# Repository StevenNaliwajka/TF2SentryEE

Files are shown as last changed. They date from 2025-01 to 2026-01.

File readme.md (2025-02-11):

# NOT COMPLETE. In PROGRESS.

### To the ATF, It is structurally impossible for this design to be used with a real weapon and is not our goal. I am a law-abiding citizen.
### To Lockheed Martin, call me...
## Documentation is NOT complete. In progress
# TF2Sentry
This is the final piece of a project with [Maiikiru](https://github.com/Maiikiru) and Bradon
to create a fully functioning level one sentry from TF2 using an AIRSOFT gun.

Inbetween classes and work each of us have put countless hours into creating a cool project.

The work can be broken up into 3 repos.
- [Maiikiru's CV Repo](https://github.com/Maiikiru/TF2SentrySource) for the brain and the logic (PRIVATE for now)
- [Bradon's CAD Repo](https://github.com/ConvexBurrito5/TF2SentryCAD) for the physical CAD/STL files (PRIVATE for now)
- [Current Repo](https://github.com/ConvexBurrito5/TF2SentryEE) for circuitry and build instructions.

This repo is my work (Steven Naliwajka/ConvexBurrito5), [GitHub](https://github.com/ConvexBurrito5), [LinkedIn](https://www.linkedin.com/in/steven-naliwajka-69564929a/).

### Two options for targeting: 
1) Maiikiru has gone through and created a Computer vision (CV) repo that automatically detects and targets people: [Maiikiru's CV Repo](https://github.com/Maiikiru/TF2SentrySource)
2) I have also gone and created a remote control, [a slightly modified wrangler](https://www.youtube.com/watch?v=LYPzGNSfVRk)

To jump straight into building, see the Documentation folder.

sentry
wrangler

## Review of my learned Skills
- At a high level, what we are trying to accomplish is simple however, as always, implementation is not as easy. I have learned lots:
  - Communication!
    - I2C Communication, learned how to implement and write code to utilize it in python.
    - Radio, utilizing 2.4Ghz wireless transceiver modules to talk from the turret to the wrangler
  - Power!
    - The turret and wrangler run off batteries.
    - 7.6v, 12v, 9.2v was all required. Got to use Buck DC voltage regulators.
    - Load calculation to make sure at least 5 hours of battery life.
  - Circuitry!
    - Circuitry to be able to plug in the turret without removing the battery. Same for Wrangler.
    - Performed proper wire size calculations; by working out max amps through each.
  - Coding!
    - Python - My first real project in python. I'm typically a java slob, so it was a little bit of a culture shock. But I'm glad I got to learn.
    - Arduino(C++) - Got to continue to hone my skills.
    - Git - I was dragged into the 21st century by Maiikiru. I'm proficient at Git now.
  - 3D Design!
    - Solidworks - I am competent at solidworks now.
  - Improved my 3D printing troubleshooting skills... and gotten a sizeable print farm out of it (2 decked out Ender 3s)
  - Working with Motors/Servos with control from both I2C and PWM.

With that out of the way, lets look into what we have completed.
## Features of the project
- Detection and tracking of a person, See [Maiikiru's CV Repo](https://github.com/Maiikiru/TF2SentrySource)
- We have provided [Maiikiru's CV Repo](https://github.com/Maiikiru/TF2SentrySource) with standard API interfaces so it easy to implement multiple hardware solutions. So far:
  - Raspberry Pi 5 (Please do not use a pi4, we tried to make it work, the performance is not good) , See 'instructionFT232H.md'
  - Standard laptop using [Adafruit's FT232H Breakout](https://www.adafruit.com/product/2264), See 'instructionRaspberryPi4.md'
- There are 4 interfaces implemented in each solution
  - FiringController
    - Handles the firing by pulling logic high on a switch to bridge the motor on the airsoft gun.
  - MotorController
    - Handles all motion. Basic set of methods to move your servos.
    - Idle motion, pans slowly looking for people.
  - PeripheralController
    - Handles the leds
  - SoundController
    - Handles all the sound, runs off of the devices default speaker.
- If a switch on the wrangler is turned on, automatic movement from [Maiikiru's CV Repo](https://github.com/Maiikiru/TF2SentrySource) will be disabled and overruled.
  - Input will be solely from the joystick and the firing button on the Wrangler.

## How can you build one?
Good news! Through many sleepless nights of documentation I have
compiled instructions to build your own TF2 Turret. You can begin by 
heading to the Documentation folder

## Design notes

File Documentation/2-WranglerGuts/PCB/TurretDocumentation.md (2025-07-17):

PCB fabrication

Fast charging of 12V Lead Acid battery.
- [CN3722 Datasheet](https://www.alldatasheet.com/datasheet-pdf/pdf/1132128/CONSONANCE/CN3722.html)

USB version is differnt than PD version.
USB w/ PD 3.1 is the 'biggest power delivery' 
- 48V 5A through USB-C

Drop it down to an acceptible charging current

LeadACID battery charging current is safe @ .3(C) charging rate
where C = Amp Hours of the battery.

How to know the AH of the battery?
If given RC (Reserve Capacity) - How long the battery can cary a 25A amp draw before dropping to 10.5V.

AH = RC(min) * 25/ 60
taking the RC of a battery off [walmart](https://duckduckgo.com/y.js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)
It can sustain for 120 minutes.

so the ah (120 * 25) / 60 = 50 AH

TODO:
GET spec for CN3722
Should I use a battery not designed for CARS?
Would that give me more AH?
What is a 'general' way to go about the batteries to meet all edge cases.

POWER:
- USB3.0 w/ PD3 or PD3.1
  - Determine if that much power is worth it.
  - Verify that it is 'backwards compatable'
    - Usb 2.0 or Usb w/o PD will still allow the equipment to function.
- Convert power to 28 volts.
  - IF PD3. NO need for this, CN3722 will take the 20V.
  - If PD3.1, Need voltge drop from 48V to X?
- Charge the car battery w/ CN3722. 
  - Utilize CCCA (Coulomb Counting + Current Control Algorithm)
    - Try an implement in hardware. Worst case, link to the Main controller (ft232h)
  - Figure out max current allowed. 
    - I dont know the size of battery.
    - I dont know the AH.
    - Assume its a Lead Acid car battery still.
    - Want to get the max throughput and take advantage of supported.

BRAIN:
- Assume using FT232H for the Brain.
- Use SPI for communication protocol:
  - SPI will allow the elimination of the aurduino chip from the circuit
  - Motor Controller + nLRF24L01 will both use SPI

RADIO: 
- Assume nLRF24L01 + helper chip.
- However, Run it through SPI. 
  - I used I2C before, verify that it will work properly.

Motor Controller:
- Find an acceptable Motor controller to control two (2) PWM managed servo motors.

Switching:
- Use mosfets to switch power quickly and effectively.
-

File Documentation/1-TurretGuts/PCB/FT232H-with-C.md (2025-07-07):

Consider the idea of instead of writing w/ Python write on C
[EX of writing in C](https://www.instructables.com/FTDI-in-C/)

- NRFL01 + FT232H (SPI) + SPI MOTOR CONTROLLER 

Possible SPI motor controllers:
TMC2130, DRV8711  : Only listed few. Google.

NRFL + FT232H
[thread #1](https://www.reddit.com/r/AskElectronics/comments/1b0ci9l/nrf24l01_module_with_adafruit_ft232h/)
[thread #2](https://arduino.stackexchange.com/questions/30719/how-to-program-an-nrfl01-rf-module-that-is-connected-to-a-pc-via-a-usb-to-uart-t)
[pastebin?](https://pastebin.com/p71255yJ)

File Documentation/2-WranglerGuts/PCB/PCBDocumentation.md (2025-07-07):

Lots of references here:

5V to 3.3V regulator:
- AMS1117 is whats used in the standard "nRF24L01+PA+LNA" 5->3.3V dedicated supply.
- [AMS1117 DOCS](http://www.advanced-monolithic.com/pdf/ds1117.pdf)
- [AMS1117 EX Circuit](https://theorycircuit.com/power-circuits/voltage-regulator-circuit-5v-to-3-3v/)  

BATTERY -> 5V Regulator:
 - [MT3608 DOCS](https://www.olimex.com/Products/Breadboarding/BB-PWR-3608/resources/MT3608.pdf)
 - [MT3608 EX Circuit](https://electronics.stackexchange.com/questions/477651/mt3608-improper-output-voltage)
 - [MT3608 Fixed 5V Thread](https://www.reddit.com/r/AskElectronics/comments/1fnrpkk/mt3608_fixed_5v_output/)
 - [Selecting an Inductor DOCS](https://www.monolithicpower.com/media/document/AN122%20Selecting%20a%20Boost%20Regulator%20and%20Its%20Inductor.pdf)
 - 

Battery MGMT Circuit + Load Sharing:
- [load sharing support thread](https://forum.arduino.cc/t/solar-li-ion-charging-with-power-path-load-sharing/602451)
- [load sharing thread #2](https://electronics.stackexchange.com/questions/591555/tp4056-with-load-sharing)
- [formal load sharing writeup](https://www.thanassis.space/loadsharing.html)
- [formal load sharing writeup #2](https://blog.zakkemble.net/a-lithium-battery-charger-with-load-sharing/)
- [load sharing thread #3](https://forum.arduino.cc/t/tp4056-lithium-charger-module-modification-to-add-power-sharing/1008473)
- [TP4056 load sharing writeup #3](https://www.best-microcontroller-projects.com/tp4056-page2.html)
- [TP4056 load sharing thread #4](https://www.reddit.com/r/PrintedCircuitBoard/comments/1k89rtd/tp4056_modul_and_load_charing_circuit/)
- [TP4056 load sharing thread #5](https://electronics.stackexchange.com/questions/628664/do-these-tp4056-charging-boards-have-built-in-load-sharing)
- [TP4056 voltage output thread](https://www.reddit.com/r/AskElectronics/comments/gyblxk/what_voltage_can_the_tp4056_output/)

nLRF24L01 Radio Circuit:
- [Example Circuit](https://imgur.com/a/0xGPQbj)
- [nLRF24L01 DOCS](https://cdn.sparkfun.com/assets/3/d/8/5/1/nRF24L01P_Product_Specification_1_0.pdf)
- USE RP-SMA connector?
- [Breakout nLRF24L01](https://www.amazon.com/UMLIFE-NRF24L01-Transceiver-Wireless-Regulator/dp/B096DLGV8F)
- [Logic LEVEL shifting Thread](https://forum.arduino.cc/t/nrf24l01-pa-lna-level-shifting/1052803)
- 

ATMEGA32u4 + USBC for flashing.
- [Minimal Circuit](https://image.easyeda.com/components/396fc048a63048f4991b64bf148cbc53.png)
- [USB-C + ATmega32u4 thread](https://electronics.stackexchange.com/questions/624732/connecting-usb-c-port-with-atmega32u4-questions)
- [USB + ATmega32u4 thread #2](https://forum.arduino.cc/t/atmega32u4-usb-powered-minimal-bootloader-and-test-circuit/437689)
- [USB-C Pinout](https://www.wandkey.com/wp-content/uploads/2024/01/usb-c-pinout-diagram.png)
- [Atmega32U4RC Bootloader Thread](https://forum.arduino.cc/t/does-atmega32u4rc-au-ic-come-with-bootloader/1069773/25)
- [ATmega32u4 Base Circuit Thread](https://forum.arduino.cc/t/atmega32u4-basic-circuit-power-supply-question/543325)
- [ATmega34U4 DOCS](https://ww1.microchip.com/downloads/en/devicedoc/atmel-7766-8-bit-avr-atmega16u4-32u4_datasheet.pdf)
- [ATmega34u4 BareBones Circuit](https://forum.arduino.cc/t/atmels-atmega-32u4/158473/2)
- [USB-C Pulldown resistors](https://www.reddit.com/r/AskElectronics/comments/18svx8z/usb_typec_receptacle_can_i_connect_both_cc1_and/)
-

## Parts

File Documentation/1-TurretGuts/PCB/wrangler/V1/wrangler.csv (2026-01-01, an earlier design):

Id | Designator | Footprint | Quantity | Designation | Supplier and ref
1 | C10 | C_0201_0603Metric | 1 | 33nF
2 | D1,D3,D2,D4 | D_SMA | 4 | SS14
3 | C17,C20,C19,C18 | C_0201_0603Metric | 4 | 1pF
4 | D12,D10,D9,D11 | LED_0805_2012Metric | 4 | LED
5 | C22,C21,C29,C32,C1 | C_0201_0603Metric | 5 | .1uF
6 | C16 | C_0201_0603Metric | 1 | .3pF
7 | Q2 | SOT-23 | 1 | AO3401A
8 | C14,C8 | C_0201_0603Metric | 2 | 10nF
9 | R8,R6 | C_0805_2012Metric | 2 | 1k
10 | L3 | C_0201_0603Metric | 1 | 3.9nH
11 | R12,R13,R2,R1 | C_0805_2012Metric | 4 | 1K
12 | R3,R9 | C_0805_2012Metric | 2 | 1.2K
13 | R5 | C_0805_2012Metric | 1 | 22k
14 | R10 | C_0805_2012Metric | 1 | 220
15 | L5 | L_1206_3216Metric | 1 | 4.7uH
16 | C28,C26,C25,C27 | C_0201_0603Metric | 4 | 10uF
17 | R14 | C_0805_2012Metric | 1 | 100
18 | U8 | SOT-23-6 | 1 | DW01A
19 | R16,R17 | C_0805_2012Metric | 2 | 10K
20 | L2,L6,L4 | C_0201_0603Metric | 3 | 2.7nH
21 | C6 | C_0201_0603Metric | 1 | 1.5pF
22 | C23,C24 | C_0201_0603Metric | 2 | 22uF
23 | U9 | SOT-23-6 | 1 | MT3608
24 | C30,C11,C12,C31 | C_0201_0603Metric | 4 | 22pF
25 | R19 | C_0805_2012Metric | 1 | 330
26 | J-LED1,J-Trigger1,J-BattLED1,J-18650,J-Spare1 | 353170221 | 5 | 35317-0221
27 | R7 | C_0805_2012Metric | 1 | 2k
28 | U5 | QFN50P300X300X60-17N | 1 | RFX2401C
29 | C7 | C_0201_0603Metric | 1 | 1.0pF
30 | R15 | C_0805_2012Metric | 1 | 32.4K
31 | U6 | SOT-223-3_TabPin2 | 1 | AMS1117
32 | C5 | C_0201_0603Metric | 1 | 4.7pf
33 | C4 | C_0201_0603Metric | 1 | 2.2nF
34 | R18,R11 | C_0805_2012Metric | 2 | 5.1K
35 | J1 | USB_C_Receptacle_HRO_TYPE-C-31-M-12 | 1 | USB_C_Receptacle
36 | C9 | C_0201_0603Metric | 1 | 1nF
37 | J-Joystick1 | RHDR6W107P420_2X3_1380X960X1310P | 1 | 35317-0620
38 | C13 | C_0201_0603Metric | 1 | 220pF
39 | Y2,Y1 | Crystal_SMD_3225-4Pin_3.2x2.5mm | 2 | 16MHz
40 | U2 | SOIC-8-1EP_3.9x4.9mm_P1.27mm_EP2.41x3.3mm_ThermalVias | 1 | TP4056-42-ESOP8
41 | J-PowerSwitch1 | SHDR4W107P420_2X2_960X960X1280P | 1 | 35317-0420
42 | C15 | C_0201_0603Metric | 1 | 1uF
43 | U4 | QFN-20-1EP_4x4mm_P0.5mm_EP2.5x2.5mm | 1 | nRF24L01P
44 | L1 | C_0201_0603Metric | 1 | 8.2nH
45 | J2 | SMA_Amphenol_132289_EdgeMount | 1 | SMA-RP
46 | Q3 | SOT-23-6 | 1 | FS8205A
47 | U3 | TQFP-44_10x10mm_P0.8mm | 1 | ATmega32U4-A

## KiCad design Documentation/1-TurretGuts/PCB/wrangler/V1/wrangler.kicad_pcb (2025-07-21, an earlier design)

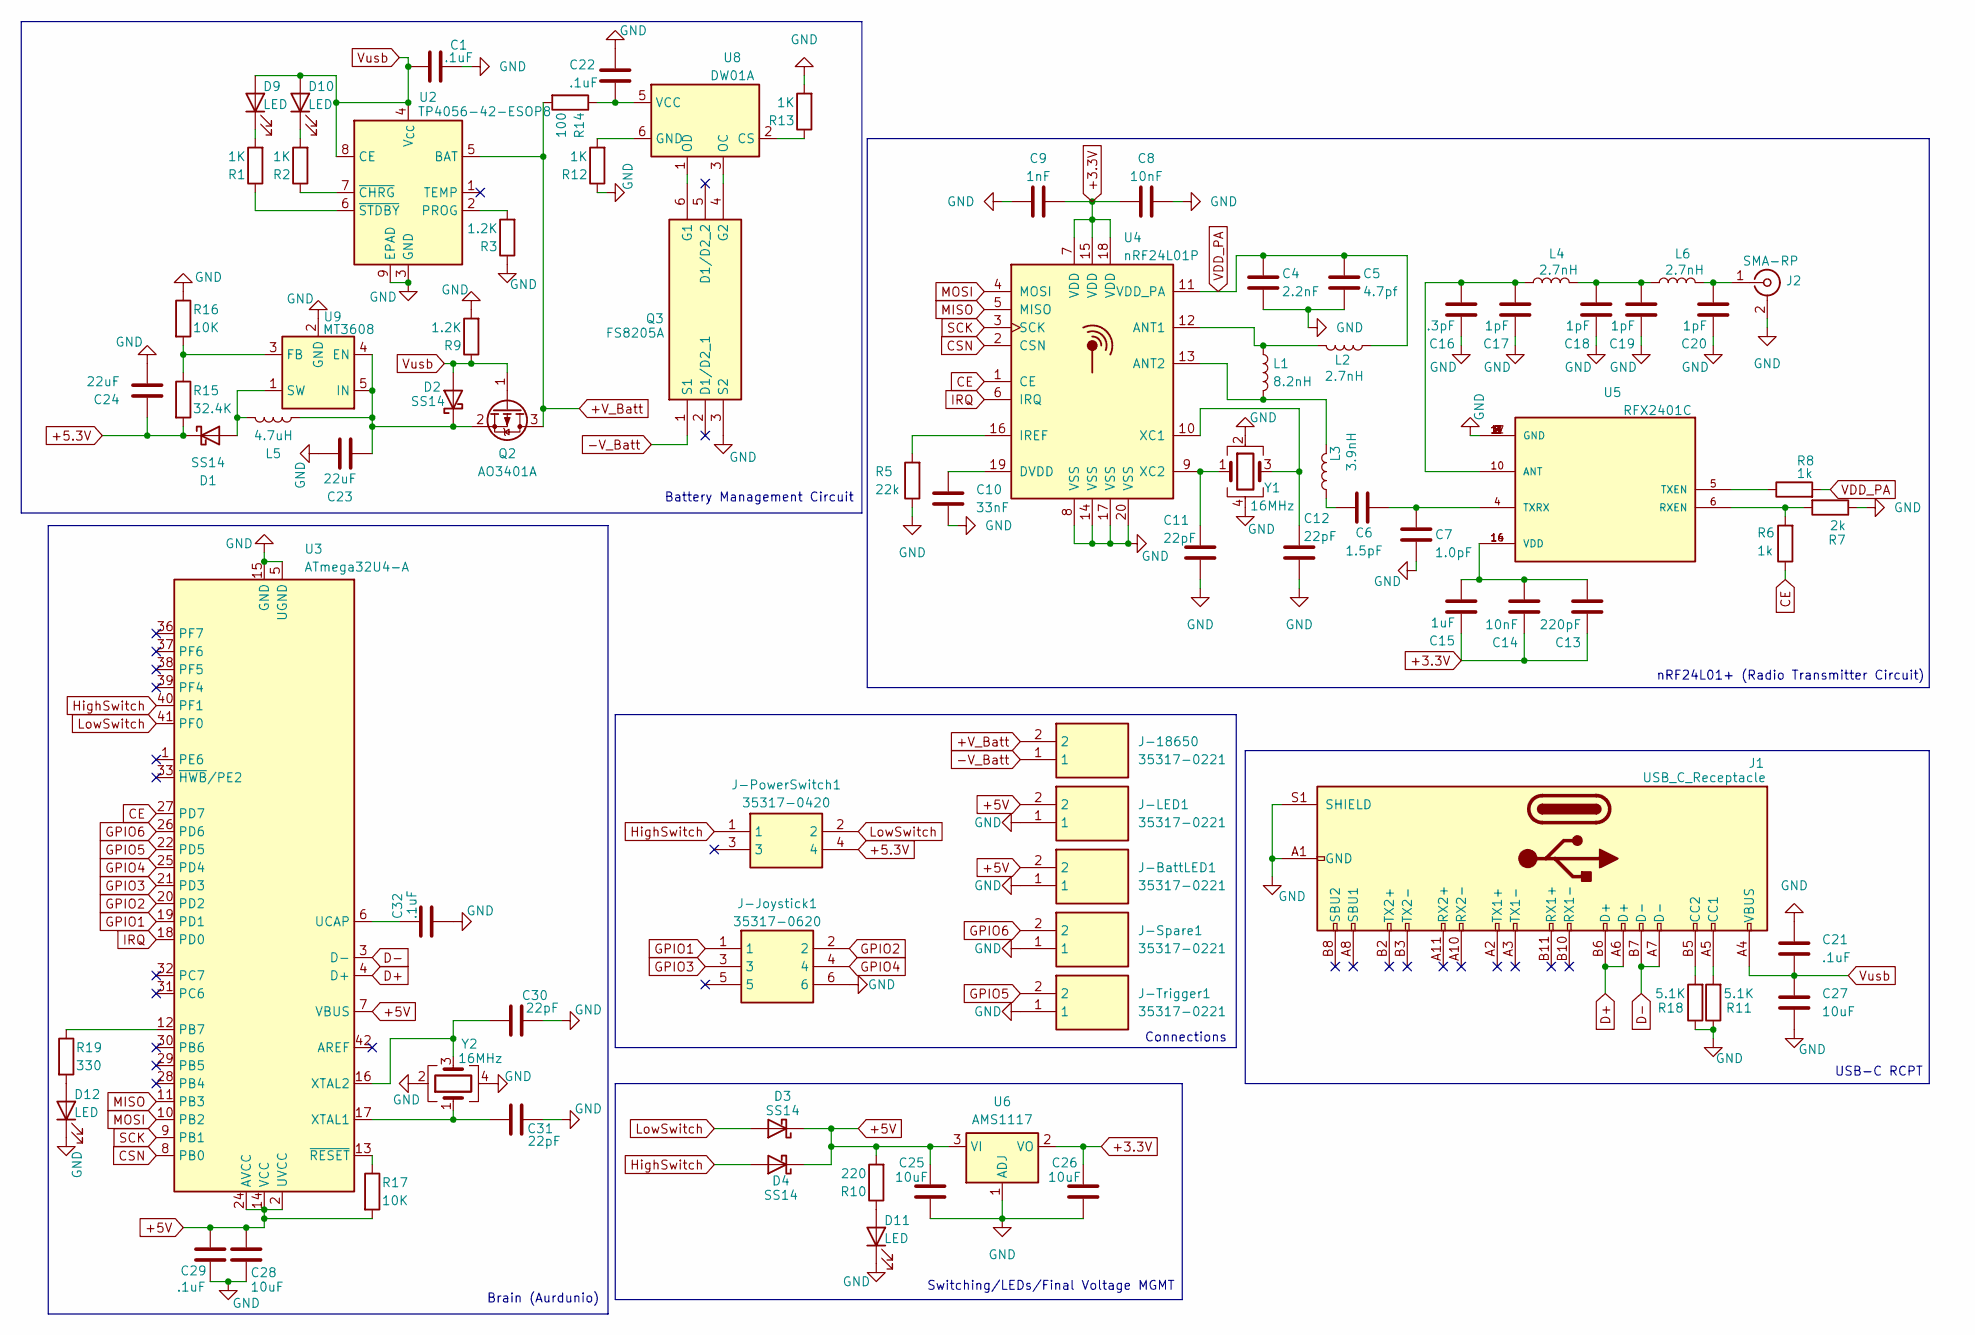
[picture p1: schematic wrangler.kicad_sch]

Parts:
C1, C21, C22, C29, C32: .1uF; C_0201_0603Metric
C4: 2.2nF; C_0201_0603Metric
C5: 4.7pf; C_0201_0603Metric
C6: 1.5pF; C_0201_0603Metric
C7: 1.0pF; C_0201_0603Metric
C8, C14: 10nF; C_0201_0603Metric
C9: 1nF; C_0201_0603Metric
C10: 33nF; C_0201_0603Metric
C11, C12, C30, C31: 22pF; C_0201_0603Metric
C13: 220pF; C_0201_0603Metric
C15: 1uF; C_0201_0603Metric
C16: .3pF; C_0201_0603Metric
C17, C18, C19, C20: 1pF; C_0201_0603Metric
C23, C24: 22uF; C_0201_0603Metric
C25, C26, C27, C28: 10uF; C_0201_0603Metric
D1, D2, D3, D4: SS14; D_SMA
D9, D10, D11, D12: LED; LED_0805_2012Metric
J1: USB_C_Receptacle; USB_C_Receptacle_HRO_TYPE-C-31-M-12
J2: SMA-RP; SMA_Amphenol_132289_EdgeMount
J-18650: 35317-0221; 353170221; Manufacturer_Part_Number 35317-0221; Mouser Part Number 538-35317-0221
J-BattLED1: 35317-0221; 353170221; Manufacturer_Part_Number 35317-0221; Mouser Part Number 538-35317-0221
J-Joystick1: 35317-0620; RHDR6W107P420_2X3_1380X960X1310P; Manufacturer_Part_Number 35317-0620; Mouser Part Number 538-35317-0620
J-LED1: 35317-0221; 353170221; Manufacturer_Part_Number 35317-0221; Mouser Part Number 538-35317-0221
J-PowerSwitch1: 35317-0420; SHDR4W107P420_2X2_960X960X1280P; Manufacturer_Part_Number 35317-0420; Mouser Part Number 538-35317-0420
J-Spare1: 35317-0221; 353170221; Manufacturer_Part_Number 35317-0221; Mouser Part Number 538-35317-0221
J-Trigger1: 35317-0221; 353170221; Manufacturer_Part_Number 35317-0221; Mouser Part Number 538-35317-0221
L1: 8.2nH; C_0201_0603Metric
L2, L4, L6: 2.7nH; C_0201_0603Metric
L3: 3.9nH; C_0201_0603Metric
L5: 4.7uH; L_1206_3216Metric
Q2: AO3401A; SOT-23
Q3: FS8205A; SOT-23-6; Manufacturer_Part_Number FS8205A
R1, R2, R12, R13: 1K; C_0805_2012Metric
R3, R9: 1.2K; C_0805_2012Metric
R5: 22k; C_0805_2012Metric
R6, R8: 1k; C_0805_2012Metric
R7: 2k; C_0805_2012Metric
R10: 220; C_0805_2012Metric
R11, R18: 5.1K; C_0805_2012Metric
R14: 100; C_0805_2012Metric
R15: 32.4K; C_0805_2012Metric
R16, R17: 10K; C_0805_2012Metric
R19: 330; C_0805_2012Metric
U2: TP4056-42-ESOP8; SOIC-8-1EP_3.9x4.9mm_P1.27mm_EP2.41x3.3mm_ThermalVias
U3: ATmega32U4-A; TQFP-44_10x10mm_P0.8mm
U4: nRF24L01P; QFN-20-1EP_4x4mm_P0.5mm_EP2.5x2.5mm
U5: RFX2401C; QFN50P300X300X60-17N
U6: AMS1117; SOT-223-3_TabPin2
U8: DW01A; SOT-23-6
U9: MT3608; SOT-23-6
Y1, Y2: 16MHz; Crystal_SMD_3225-4Pin_3.2x2.5mm

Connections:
+3.3V: C8.1, C9.2, C13.2, C14.2, C15.2, C26.1, U4.7 (VDD), U4.15 (VDD), U4.18 (VDD), U6.2 (VO)
+5.3V: C24.2, D1.1 (K), J-PowerSwitch1.4, R15.2
+5V: C25.1, C28.1, C29.1, D3.1 (K), D4.1 (K), J-BattLED1.2, J-LED1.2, R10.2, R17.2, U3.2 (UVCC), U3.7 (VBUS), U3.14 (VCC), U3.24 (AVCC), U3.34 (VCC), U3.44 (AVCC), U6.3 (VI)
+V_Batt: J-18650.2, Q2.3 (D), R14.2, U2.5 (BAT)
-V_Batt: J-18650.1, Q3.1 (S1)
CE: R6.1, U3.27 (PD7), U4.1 (CE)
CSN: U3.8 (PB0), U4.2 (CSN)
D+: J1.A6 (D+), J1.B6 (D+), U3.4 (D+)
D-: J1.A7 (D-), J1.B7 (D-), U3.3 (D-)
GND: C1.2, C4.2, C5.2, C7.1, C8.2, C9.1, C10.2, C11.2, C12.2, C16.2, C17.2, C18.2, C19.2, C20.2, C21.1, C22.1, C23.2, C24.1, C25.2, C26.2, C27.2, C28.2, C29.2, C30.2, C31.2, C32.2, D11.1 (K), D12.1 (K), J1.A1 (GND), J1.A12 (GND), J1.B1 (GND), J1.B12 (GND), J1.S1 (SHIELD), J2.2 (Ext), J-BattLED1.1, J-Joystick1.6, J-LED1.1, J-Spare1.1, J-Trigger1.1, Q3.3 (S2), R3.1, R5.1, R7.1, R9.2, R11.1, R12.1, R13.2, R16.1, R18.1, U2.3 (GND), U2.9 (EPAD), U3.5 (UGND), U3.15 (GND), U3.23 (GND), U3.35 (GND), U3.43 (GND), U4.8 (VSS), U4.14 (VSS), U4.17 (VSS), U4.20 (VSS), U5.2 (GND), U5.3 (GND), U5.8 (GND), U5.9 (GND), U5.11 (GND), U5.17 (GND), U6.1 (ADJ), U9.2 (GND), Y1.2, Y1.4, Y2.2, Y2.4
GPIO1: J-Joystick1.1, U3.19 (PD1)
GPIO2: J-Joystick1.2, U3.20 (PD2)
GPIO3: J-Joystick1.3, U3.21 (PD3)
GPIO4: J-Joystick1.4, U3.25 (PD4)
GPIO5: J-Trigger1.2, U3.22 (PD5)
GPIO6: J-Spare1.2, U3.26 (PD6)
HighSwitch: D4.2 (A), J-PowerSwitch1.1, U3.40 (PF1)
IRQ: U3.18 (PD0), U4.6 (IRQ)
LowSwitch: D3.2 (A), J-PowerSwitch1.2, U3.41 (PF0)
MISO: U3.11 (PB3), U4.5 (MISO)
MOSI: U3.10 (PB2), U4.4 (MOSI)
unnamed: C6.1, L3.1
unnamed: C13.1, C14.1, C15.1, U5.14 (VDD), U5.16 (VDD)
unnamed: C18.1, C19.1, L4.2, L6.1
unnamed: D1.2 (A), L5.2, U9.1 (SW)
unnamed: C23.1, D2.1 (K), L5.1, Q2.2 (S), U9.4 (EN), U9.5 (IN)
unnamed: D9.1 (K), R1.2
unnamed: D10.1 (K), R2.2
unnamed: D11.2 (A), R10.1
unnamed: D12.2 (A), R19.2
unnamed: J1.A5 (CC1), R11.2
unnamed: J1.B5 (CC2), R18.2
unnamed: C20.1, J2.1 (In), L6.2
unnamed: Q3.6 (G1), U8.1 (OD)
unnamed: Q3.4 (G2), U8.3 (OC)
unnamed: R3.2, U2.2 (PROG)
unnamed: R2.1, U2.7 (~CHRG)
unnamed: R1.1, U2.6 (~STDBY)
unnamed: R19.1, U3.12 (PB7)
unnamed: C32.1, U3.6 (UCAP)
unnamed: C31.1, U3.17 (XTAL1), Y2.1
unnamed: C30.1, U3.16 (XTAL2), Y2.3
unnamed: R17.1, U3.13 (~RESET)
unnamed: L1.1, L2.2, U4.12 (ANT1)
unnamed: L1.2, L3.2, U4.13 (ANT2)
unnamed: C10.1, U4.19 (DVDD)
unnamed: R5.2, U4.16 (IREF)
unnamed: C12.1, U4.10 (XC1), Y1.3
unnamed: C11.1, U4.9 (XC2), Y1.1
unnamed: C16.1, C17.1, L4.1, U5.10 (ANT)
unnamed: R6.2, R7.2, U5.6 (RXEN)
unnamed: R8.1, U5.5 (TXEN)
unnamed: C6.2, C7.2, U5.4 (TXRX)
unnamed: R13.1, U8.2 (CS)
unnamed: R12.2, U8.6 (GND)
unnamed: C22.2, R14.1, U8.5 (VCC)
unnamed: R15.1, R16.2, U9.3 (FB)
SCK: U3.9 (PB1), U4.3 (SCK)
VDD_PA: C4.1, C5.1, L2.1, R8.2, U4.11 (VDD_PA)
Vusb: C1.1, C21.2, C27.1, D2.2 (A), D9.2 (A), D10.2 (A), J1.A4 (VBUS), J1.A9 (VBUS), J1.B4 (VBUS), J1.B9 (VBUS), Q2.1 (G), R9.1, U2.4 (V_{CC}), U2.8 (CE)

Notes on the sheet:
Brain (Aurdunio)
Battery Management Circuit
nRF24L01+ (Radio Transmitter Circuit)
Connections
Switching/LEDs/Final Voltage MGMT
USB-C RCPT

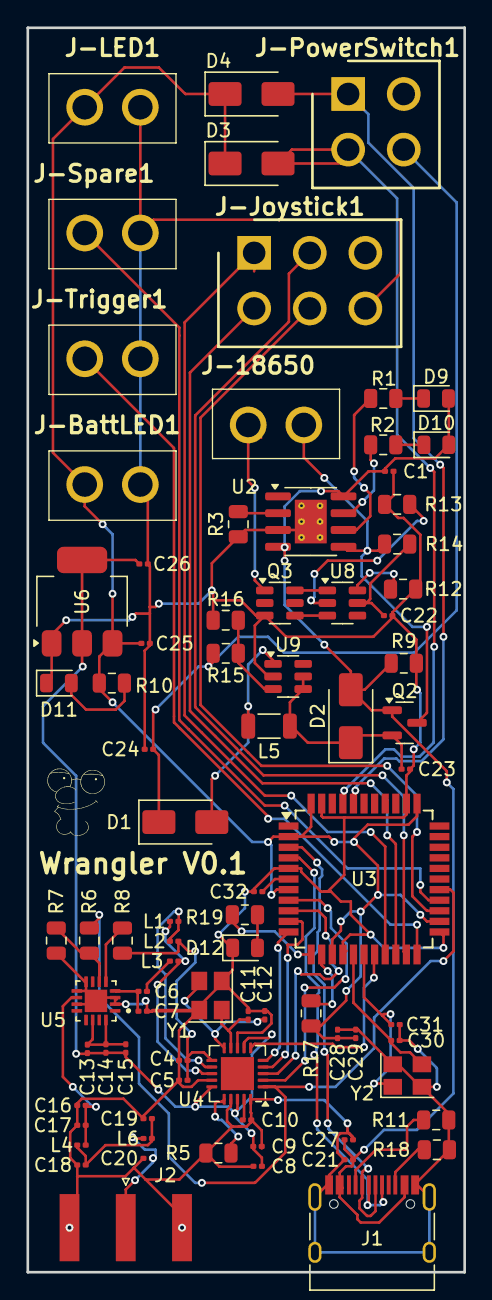
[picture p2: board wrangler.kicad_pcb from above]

Board: 2 copper layers, 33.0 x 94.0 mm, 82 parts (0 on the bottom side), 60 nets.

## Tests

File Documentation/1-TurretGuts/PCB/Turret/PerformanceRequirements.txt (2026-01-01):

Main Board for Turret.

- Parent, Receive data to main turret board.

INPUT:
- 1 12V + GND for Battery Array
- 1 12V + GND for Power Switch

OUTPUT:
- 1 GPIO + GND for LED
- 1 GPIO + GND for Lazer

output:
- 1 GPIO + GND for battery display.
- 1 GPIO + GND spare

MISC:
- try without antenna
- ESP32-S3-WROOM-1U-N16R8 for logic + control
- If can be charged off USB-C While it runs thats even better, 120V if else.
- Run off a battery for a while when not being used.
- 1 LED on the board for ON
- GEOPOSITIONING with the chip

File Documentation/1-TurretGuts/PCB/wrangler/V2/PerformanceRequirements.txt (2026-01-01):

Main Board for Wrangler.

- Remote control, send data to main turret board.

input:
- 4 GPIO + GND for Joystick.
- 1 GPIO + GND for trigger.
- 2 GPIO + GND for Power Switch.
- 1 GPIO + GND for 18650 Battery

output:
- 1 GPIO + GND for battery display.
- 1 GPIO + GND for 'on' display.
- 1 GPIO + GND spare

MISC:
- SMA antenna
- ESP32-S3-WROOM-1U-N16R8 for logic + control
- Charge while its being used.
- Run off a battery for a while when not being used.

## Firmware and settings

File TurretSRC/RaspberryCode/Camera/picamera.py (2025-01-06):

from picamera2 import Picamera2
from IO.camera import Camera
import cv2
import numpy as np


class PiCamera(Camera):
    def __init__(self, camera_num, resolution=(640, 480), cap_fps=30) -> None:
        super().__init__(resolution, cap_fps)
        self.camera = Picamera2(camera_num)
        # Note here that RGB888 is actually BGR with 8 bits for each color (as defined in the libcamera/picamera2 docs)
        # We will hardcode the sensor size here because we are using picamera module 2.
        config = self.camera.create_video_configuration(sensor={'output_size': (1640, 1232), 'bit_depth': 10},
                                                        main={"format": 'RGB888',
                                                              "size": (resolution[0], resolution[1])})
        self.camera.configure(config)
        self.camera.start()
        self.raw_frame: np.ndarray = None

    def get_frame(self) -> None:
        self.raw_frame = self.camera.capture_array()

    def decode_frame(self) -> tuple[bool, cv2.typing.MatLike]:
        if self.raw_frame is None:
            return False, np.array([])

        return True, cv2.resize(self.raw_frame, self.RESOLUTION, interpolation=cv2.INTER_AREA)

    

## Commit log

2024-12-19 Update the camera firmware
2024-12-20 Fix the camera code to actually return the type numpy is expecting
    [picamera.py]
2024-12-20 Added camera_num param
2025-01-06 Change to use different sensor
2025-07-07 add refs for Wrangler Circuit
2025-07-07 Wrangler PCB
    [wrangler.kicad_pcb, wrangler.kicad_sch]
2025-07-17 sync with main
    [TurretMainBoard.kicad_pcb, TurretMainBoard.kicad_sch]
2025-07-21 wrangler pass 1
    [wrangler-B_Cu.gbr, wrangler-B_Mask.gbr, wrangler-B_Paste.gbr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]
